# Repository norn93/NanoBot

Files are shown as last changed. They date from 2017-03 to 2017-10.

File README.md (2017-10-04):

# ANDRIS - AutoNomous Driving Robotic Interactive System: An Open-source Arduino Nano based Robot 

ANDRIS is an educational platform for highschool and university students to use to learn about robot hardware and software.

* Deprecated: Old files tagged for deletion
* Hardware: KiCad PCB designs and libraries
* Libraries: Contains the most up to date versions of the different libraries we use
	* Debug: Library for debugging code, and for testing
	* NanoBot: The current official release
* Results: Part of our ongoing debugging and testing for the library
* Programs: Contains some example programs which make use of the NanoBot library
	* robot_move_commands: A basic sketch for Alfie. Control the robot via bluetooth and keyboard. 

## Hardware todo:
* Revise PCB to version 1.0
	
## Software todo:
* Edit library: it should only include the bare minimum it needs to function, and it should be commented clearly

## Authors
* **George Knowlden** - Initial work, PCB design
* **Kimberley Siew** - Initial work, PCB design
* **Ashwin D'Cruz** - Initial work

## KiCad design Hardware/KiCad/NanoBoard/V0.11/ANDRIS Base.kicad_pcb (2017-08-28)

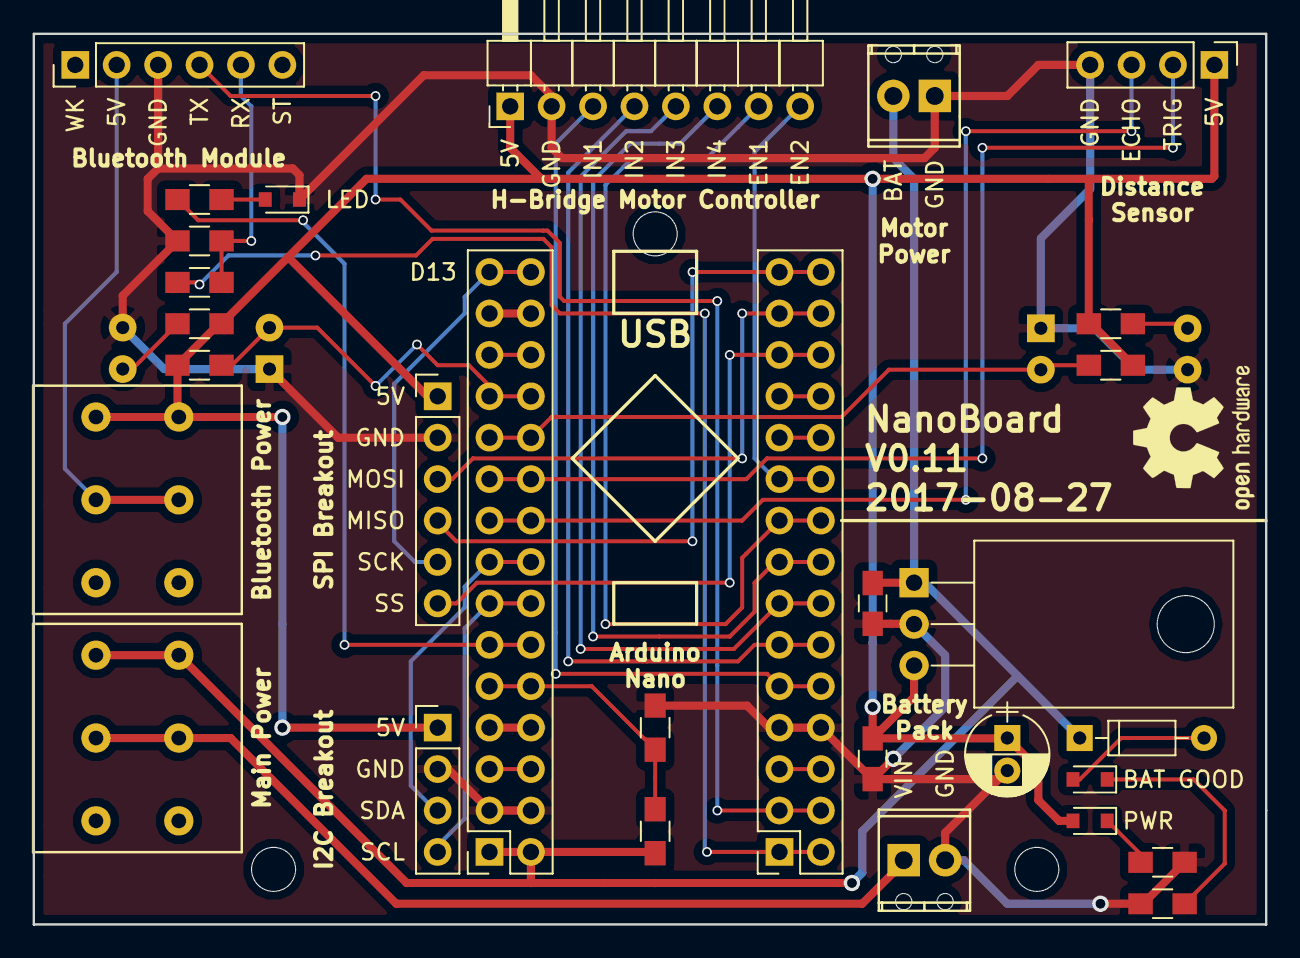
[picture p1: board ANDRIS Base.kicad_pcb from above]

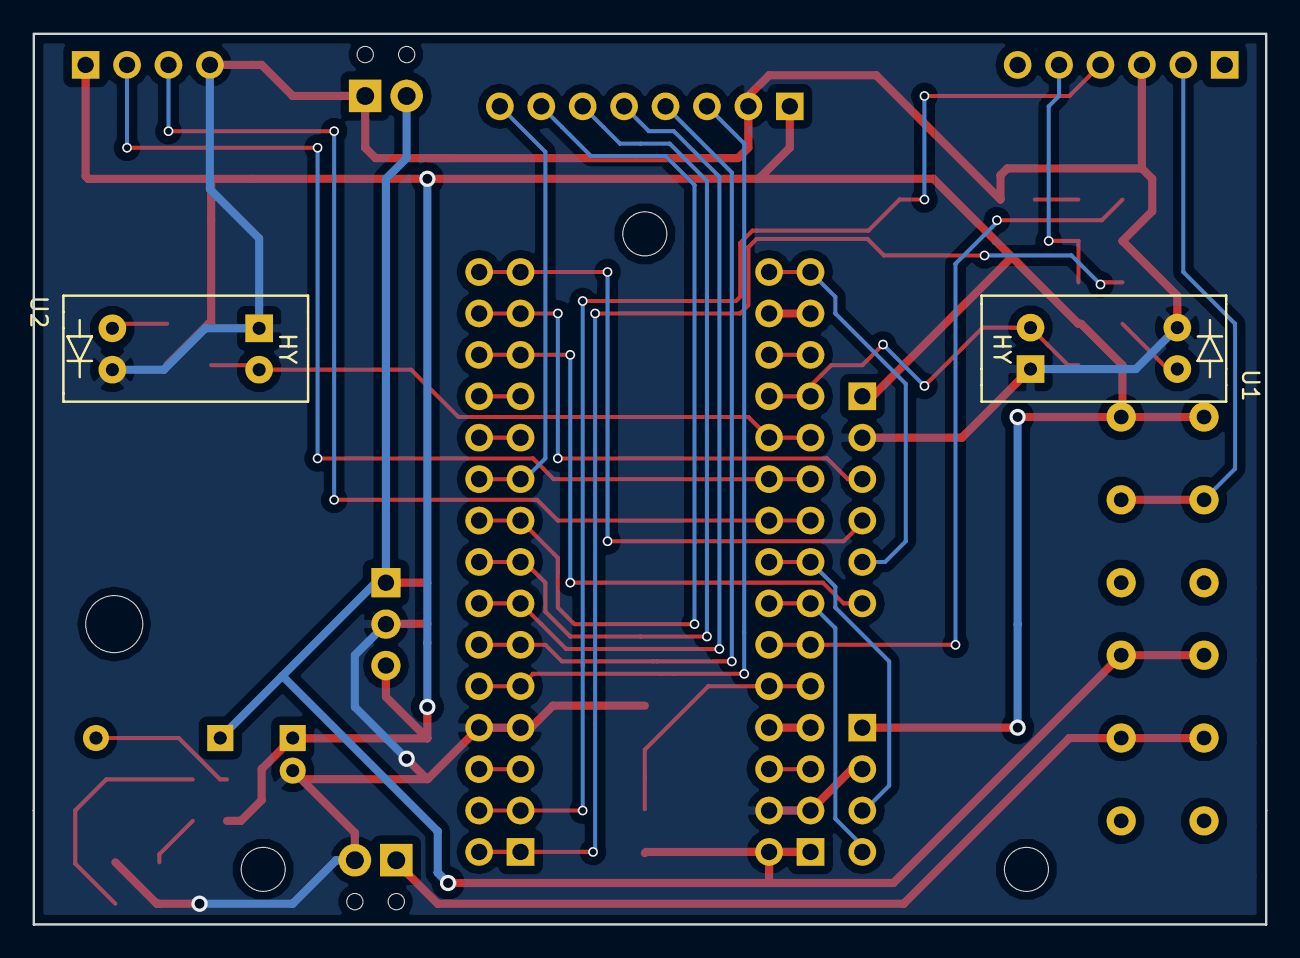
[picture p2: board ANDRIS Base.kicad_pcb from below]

Board: 2 copper layers, 75.6 x 54.6 mm, 32 parts (2 on the bottom side), 38 nets.

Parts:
C1, C2: 1u; C_0805_HandSoldering
C3: 10u; CP_Radial_D5.0mm_P2.00mm
D1: PWR; D_0805
D2: 5V1; D_DO-35_SOD27_P7.62mm_Horizontal
D3, D4: LED; D_0805
P1: H-Bridge Connector; Pin_Header_Angled_1x08_Pitch2.54mm
P2: Ultransonic Transducer; Pin_Header_Straight_1x04_Pitch2.54mm
P3: Battery Pack Connection; TerminalBlock_RS_Pro_MPT-2.54mm_2pol
P4: Nano Left; Socket_Strip_Straight_2x15_Pitch2.54mm
P5: Nano Right; Socket_Strip_Straight_2x15_Pitch2.54mm
P6: I2C Breakout; Socket_Strip_Straight_1x04_Pitch2.54mm
P7: HC-05 Bluetooth Connection; Socket_Strip_Straight_1x06_Pitch2.54mm
P8: SPI Breakout; Socket_Strip_Straight_1x06_Pitch2.54mm
P9: Motor Connection; TerminalBlock_RS_Pro_MPT-2.54mm_2pol
R1, R3, R7, R10, R11: 220R; R_0805_HandSoldering
R2, R4, R6: 1k; R_0805_HandSoldering
R5: 2.2k; R_0805_HandSoldering
R8, R9: 10K; R_0805_HandSoldering
SW1, SW2: SW_DPDT; Dailywell_DPDT_Switch
U1: Left Optocoupler; LTH-301-07
U2: Right Optocoupler; LTH-301-07
U3: 7805; TO-220_Horizontal_FIXED

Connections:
+5V: C2.1, C3.1, D1.2, P1.1, P2.1, P6.1, P8.1, R1.2, R2.2, R3.2, R4.2, SW2.1, SW2.4, U3.VO
/3V3: P5.27, P5.28
/5V: P5.7, P5.8
/A0_OPT_L: P5.23, P5.24, R2.1, U1.16
/A1_OPT_R: P5.21, P5.22, R4.1, U2.16
/A2_UT_TRIG: P2.2, P5.19, P5.20
/A3_UT_ECHO: P2.3, P5.17, P5.18
/A4_SDA: P5.15, P5.16, P6.3
/A5_SCL: P5.13, P5.14, P6.4
/A6_LED: P5.11, P5.12, R10.1
/A7_BATTERY: P5.9, P5.10, R8.2, R9.1
/BAT: C1.1, D2.1, P5.1, P5.2, P9.2, R8.1, SW1.1, SW1.4, U3.VI
/BAT-SW: P3.1, SW1.2, SW1.5
/D2_IN1: P1.3, P4.9, P4.10
/D3_IN2: P1.4, P4.11, P4.12
/D4_IN3: P1.5, P4.13, P4.14
/D5_IN4: P1.6, P4.15, P4.16
/D6_EN1: P1.7, P4.17, P4.18
/D7_EN2: P1.8, P4.19, P4.20
/D8: P4.21, P4.22
/D9: P4.23, P4.24
/D10_SS: P4.25, P4.26, P8.6
/D11_MOSI: P4.27, P4.28, P8.3
/D12_MISO: P4.29, P4.30, P8.4
/D13_SCK: P5.29, P5.30, P8.5
/REF: P5.25, P5.26
/RST: P4.5, P4.6, P5.5, P5.6
/RX: P4.3, P4.4, P7.4
/SW-BT: P7.2, SW2.2, SW2.5
/TX: P4.1, P4.2, R6.2
GND: C1.2, C2.2, C3.2, D4.1, P1.2, P2.4, P3.2, P4.7, P4.8, P5.3, P5.4, P6.2, P7.3, P8.2, P9.1, R5.1, R7.1, R9.2, R11.2, U1.2, U1.15, U2.2, U2.15, U3.GND
unnamed: D1.1, R7.2
unnamed: D2.2, D3.2
unnamed: D3.1, R11.1
unnamed: D4.2, R10.2
unnamed: P7.5, R5.2, R6.1
unnamed: R1.1, U1.1
unnamed: R3.1, U2.1

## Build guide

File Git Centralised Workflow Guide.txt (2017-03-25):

Git Centralised Workflow Guide V0.1
By George Knowlden, based on notes from https://www.atlassian.com/git/tutorials/comparing-workflows#centralized-workflow
____________________________________________________________________________________________________________________________________________

Single point-of-entry for all changes to the project: master.
No other branches are required.

Firstly, clone the central repository.

To publish a feature: fetch updated central commits and reabse their changes on top of them.
"I want to add my changes to what everyone else has done."

If there are conflicts (local changes conflict with upstream commits), Git will pause the rebase and let you manually resolve the conflicts.

You can use the "git status" and "git add" commands for both generating commits and resolving conflicts.
There is also a command to abort the rebase and try again.

INIT

1) Someone initialises the central repository (easiest to do this online)
2) Everybody clones the central repository (git clone xxxxxx)
2.3) Make sure that 
	git config merge.tool vimdiff
	git config merge.conflictstyle diff3

WORKING LOCALLY

2.5) git pull origin master (to get latest versions of files)
3) Edit files
4) git status
5) git add
6) git commit

PUBLISHING

7) git push origin master (make origins's master branch look like your local master branch)

If there are no errors, you're done! Else...

REBASING (in the case of a failure to publish)

Error looks like the following:
error: failed to push some refs to '/path/to/repo.git'
hint: Updates were rejected because the tip of your current branch is behind
hint: its remote counterpart. Merge the remote changes (e.g. 'git pull')
hint: before pushing again.
hint: See the 'Note about fast-forwards' in 'git push --help' for details.

8) git pull --rebase origin master (try to make local master branch look like origin's master)
"Rebase" moves your changes to the end, so that the pull happens first, and then Git will try to merge the files

MERGING

Trasfer local commits to updated master one at a time.

Example of error in merging:
CONFLICT (content): Merge conflict in <some-file>
9) git status (shows the location of the problem in the following format:)
# Unmerged paths:
# (use "git reset HEAD <some-file>..." to unstage)
# (use "git add/rm <some-file>..." as appropriate to mark resolution)
#
# both modified: <some-file>

10) Edit the file/s until things are good
	git mergetool
11) git add <file>
12) git rebase --continue (or --skip)
Git will now repeat for the next commit, and repeat.

If at any point from 8-12 you get stuck, run the following to take you back to before 8):
13) git rebase --abort
When you've finished 12) for the last time, you can run 7)

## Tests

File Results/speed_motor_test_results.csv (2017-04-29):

 | microseconds
 | Start speed test…
0 | 4
1 | 59564
2 | 89516
3 | 115296
4 | 138700
5 | 160728
6 | 181584
7 | 201984
8 | 222252
9 | 242228
10 | 261908
11 | 281308
12 | 300260
13 | 319596
14 | 338488
15 | 357396
16 | 376440
17 | 394720
18 | 413772
19 | 432252
20 | 451500
21 | 469540
22 | 487620
23 | 506204
24 | 525060
25 | 543824
26 | 562036
27 | 580824
28 | 599592
29 | 618316
30 | 637260
31 | 655664
32 | 674128
33 | 692784
34 | 711380
35 | 729740
36 | 748224
37 | 766340
38 | 785244
39 | 803624
40 | 822876
41 | 840568
42 | 858300
43 | 876876
44 | 895744
45 | 914276
46 | 932244
47 | 951000
48 | 969792
49 | 988408 | Switch off motor
50 | 1007264
51 | 1026420
52 | 1047008
53 | 1070084
54 | 1094584
55 | 1121708
56 | 1151836
57 | 1185844
58 | 1229216
59 | 1284592
60 | 1392012
 | Stop speed test.

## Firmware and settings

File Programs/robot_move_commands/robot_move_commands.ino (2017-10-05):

#include "NanoBot.h"

void setup() {
  NanoInitialise();
  Serial.println("I'm alive");
}

void serialEvent() {
  //gets the serial input from the BT module
  //does this once per loop automatically
  //(read arduino docs for serialEvent() )
  while (Serial.available()) {
    char inCommand =  (char)Serial.read();
    if (inCommand == 'w') {
      NanoForward(500);
    }
    if (inCommand == 's') {
      NanoBackward(500);
    }
    if (inCommand == 'a') {
      NanoTurn('l', 150);
    }
    if (inCommand == 'd') {
      NanoTurn('r', 150);
    }
  }
}

void test() {
  return;
}

void loop() {
  // put your main code here, to run repeatedly:
}

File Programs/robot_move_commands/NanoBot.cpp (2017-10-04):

/*
  Robot.cpp - Library to control robots
  Created by D'Cruz A., Knowlden G., Siew K., November 2015
  Last updated 2015-11-03
*/

//include header files
#include "NanoBot.h"
#include "PinChangeInt.h"

//variables
char _Nano_left_direction;
char _Nano_right_direction;

int _Nano_left_ticks;
int _Nano_left_ticks_last;
bool _Nano_debug_print_encoder_left;  //left optocoupler not working
bool _Nano_debug_print_encoder_right;
long _Nano_debug_start_time_micros;

int _Nano_right_ticks;

long _Nano_left_micros;
long _Nano_left_micros_last;

float _Nano_left_speed;

//functions
void NanoInitialise() {
  //initialise the nanoBot

  //start serial
  Serial.begin(9600);

  //initialise the motors
  _NanoInitialiseMotors();

  //initialise the optocouplers
  pinMode(OPT_L, INPUT);
  PCintPort::attachInterrupt(OPT_L, _NanoOptocouplerLeft, RISING); //only detect slits (it's 0 on slit and 1 on wood so we are detecting moving from slit to wood right?)
  pinMode(OPT_R, INPUT);
  PCintPort::attachInterrupt(OPT_R, _NanoOptocouplerRight, RISING); //only detect slits


  //initialise the interrupts
  cli(); //pause interrupts to set up sensitive stuff

  //set timer1 interrupt at 10Hz
  TCCR1A = 0;// set entire TCCR1A register to 0
  TCCR1B = 0;// same for TCCR1B
  TCNT1  = 0;//initialize counter value to 0
  // set compare match register for 100hz increments
  OCR1A = 155;// = (16*10^6) / (100*1024) - 1 (must be <65536)
  // turn on CTC mode
  TCCR1B |= (1 << WGM12);
  // Set CS10 and CS12 bits for 1024 prescaler
  TCCR1B |= (1 << CS12) | (1 << CS10);
  // enable timer compare interrupt
  TIMSK1 |= (1 << OCIE1A);

  sei(); //resume interrupts
}

void _NanoInitialiseMotors() {
  //initialise the motors according to the #defines from the header file
  pinMode(EN1, OUTPUT);
  pinMode(EN2, OUTPUT);
  pinMode(IN1, OUTPUT);
  pinMode(IN2, OUTPUT);
  pinMode(IN3, OUTPUT);
  pinMode(IN4, OUTPUT);
}

void NanoDrive(float motor_a_speed, float motor_b_speed)
{
  //Move both motors at defined speeds/directions
  //speed is truncated in the range {-1 <= speed <= 1}
  //positive speeds are forward, negative speeds are backward

  //truncate speeds
  if (motor_a_speed > 1) {
    motor_a_speed = 1;
  } else if (motor_a_speed < -1) {
    motor_a_speed = -1;
  }
  if (motor_b_speed > 1) {
    motor_b_speed = 1;
  } else if (motor_b_speed < -1) {
    motor_b_speed = -1;
  }

  boolean in1, in2, in3, in4;

  if (motor_a_speed > 0) { //forward
    in1 = LOW;
    in2 = HIGH;
    _Nano_left_direction = 0; //todo: fix this
    _Nano_right_direction = 0; //todo: fix this
  } else { //backward
    in1 = HIGH;
    in2 = LOW;
    _Nano_left_direction = 1; //todo: fix this
    _Nano_right_direction = 1; //todo: fix this
  }

  if (motor_b_speed > 0) { //forward
    in3 = LOW;
    in4 = HIGH;
    _Nano_left_direction = 0; //todo: fix this
    _Nano_right_direction = 0; //todo: fix this
  } else { //backward
    in3 = HIGH;
    in4 = LOW;
    _Nano_left_direction = 1; //todo: fix this
    _Nano_right_direction = 1; //todo: fix this
  }

  //set the motors
  digitalWrite(IN1, in1);
  digitalWrite(IN2, in2);
  digitalWrite(IN3, in3);
  digitalWrite(IN4, in4);

  //run the motors
  int speed_a = abs(motor_a_speed)*255;
  int speed_b = abs(motor_b_speed)*255;
  analogWrite(EN1, speed_a);
  analogWrite(EN2, speed_b);

}

//these next 2 functions will eventually be replaced by ones with closed loops
void NanoForward(int duration) {
  NanoDrive(1, 1);
  delay(duration);
  NanoStop();
}

void NanoBackward(int duration) {
  NanoDrive(-1, -1);
  delay(duration);
  NanoStop();
}

void NanoStop() {
  //stop moving
  NanoDrive(0, 0);
}

void NanoTurn(char turn_direction, int duration) {
  if (turn_direction == 'a' || turn_direction == 'l') {
    NanoDrive(-1, 1);
  }
  else if (turn_direction == 'd' || turn_direction == 'r') {
    NanoDrive(1, -1);
  } else {
    Serial.print("Turn direction: '");
    Serial.print(turn_direction);
    Serial.println("' not recongised.");
  }
  delay(duration);
  NanoStop();
}

void _NanoOptocouplerLeft() {
  //callback for the left optocoupler
  if (_Nano_left_direction) { //driving forward
    _Nano_left_ticks++;
  } else { //driving backward
    _Nano_left_ticks--;
  }

  if (_Nano_debug_print_encoder_left) {
    Serial.println(micros() - _Nano_debug_start_time_micros);
    //Serial.println(_Nano_left_ticks);
    //Serial.print("\t");
  }

}

void _NanoOptocouplerRight() {
  //callback for the right optocoupler
  if (_Nano_right_direction) { //driving forward
    _Nano_right_ticks++;
  } else { //driving backward
    _Nano_right_ticks--;
  }

  if (_Nano_debug_print_encoder_right) {
    Serial.println(micros() - _Nano_debug_start_time_micros);
    //Serial.println(_Nano_left_ticks);
    //Serial.print("\t");
  }
}

void _NanoMotorTest() {
  //a small function to help tune the motor controllers

  Serial.println("Start speed test...");

  //_Nano_debug_print_encoder_left = true;
  _Nano_debug_print_encoder_right = true;

  _Nano_debug_start_time_micros = micros();

  Serial.println(micros() - _Nano_debug_start_time_micros);
  //Serial.print("\t");
  //Serial.println(_Nano_left_ticks);

  NanoForward(1000);

  /*for (int i = 0; i < 100; i++) {
  	//Serial.println(_Nano_left_speed);
  	Serial.println(_Nano_left_ticks);
  	delay(5);
    }*/

  Serial.println("Switch off motor...");

  /*for (int i = 0; i < 100; i++) {
  	//Serial.println(_Nano_left_speed);
  	Serial.println(_Nano_left_ticks);
  	delay(5);
    }*/

  delay(1000);

  //_Nano_debug_print_encoder_left = false;
  _Nano_debug_print_encoder_right = false;

  Serial.println("Stop speed test.");

}
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

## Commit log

2016-03-19 adding arduino code
2016-03-19 Added debug .cpp with encoder debug
2017-03-25 Added KiCad files, updated README
    [NanoBoard.kicad_pcb, NanoBoard.sch]
2017-04-29 Commented out _Nano_debug_print_encoder_left variable, added speed test results
    [speed_motor_test_results.csv]
2017-05-06 Updated the README
    Better reflect current situation
2017-05-06 Updating tests
    Starting to compare the velocity estimates a little more accurately
2017-08-28 Added latest PCB files
    [ANDRIS Base.kicad_pcb, ANDRIS Base.sch, NanoBoard.kicad_pcb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]
2017-10-04 Updated program for version 0.11 of the board
2017-10-04 Added new program for testing the encoders
2017-10-05 Failed attempt to put the library into a class
    [ANDRIS.cpp, class_testing.ino]
